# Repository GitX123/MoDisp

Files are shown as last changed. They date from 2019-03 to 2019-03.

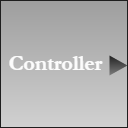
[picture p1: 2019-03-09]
back-end/MoDisp/front-end/image/fg_controller_128.png

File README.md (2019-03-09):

# MoDisp
Robust and flexible modular display system which reconfigures data paths upon hardware change

[back-end]
* Run on Raspberry Pi or C.H.I.P., act as a gateway between the web UI and the MoDisp protocol.
* Mainly contributed by e841018, and also thanks HongCheng Zheng for developing the prototype of the UI.

[controller]
* Run on ATMEGA 328
* James Chan contributed to the firmware, while e841018 designed the PCB.

[bracket]
* Designed by Onshape, publicly available at
  https://cad.onshape.com/documents/cf011c8e0843ee4877112711/w/4f09f0267c82e90f73bca7a8/e/ec47567f47b796b4294d7e92

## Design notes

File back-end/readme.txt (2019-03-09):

[wifi]
sudo nmcli device wifi connect <ssid> password <password> ifname wlan0
sudo nmcli device wifi connect "Obtaining IP address..." password 3.141592 ifname wlan0

[start]
MoDisp/init.sh

[i2cdetect]
/usr/sbin/i2cdetect -y 1

[shutdown]
sudo halt

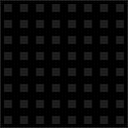
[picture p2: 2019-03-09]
back-end/MoDisp/front-end/image/bg_module_128.png

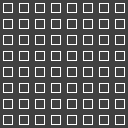
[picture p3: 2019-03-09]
back-end/MoDisp/front-end/image/fg_dbd_128.png

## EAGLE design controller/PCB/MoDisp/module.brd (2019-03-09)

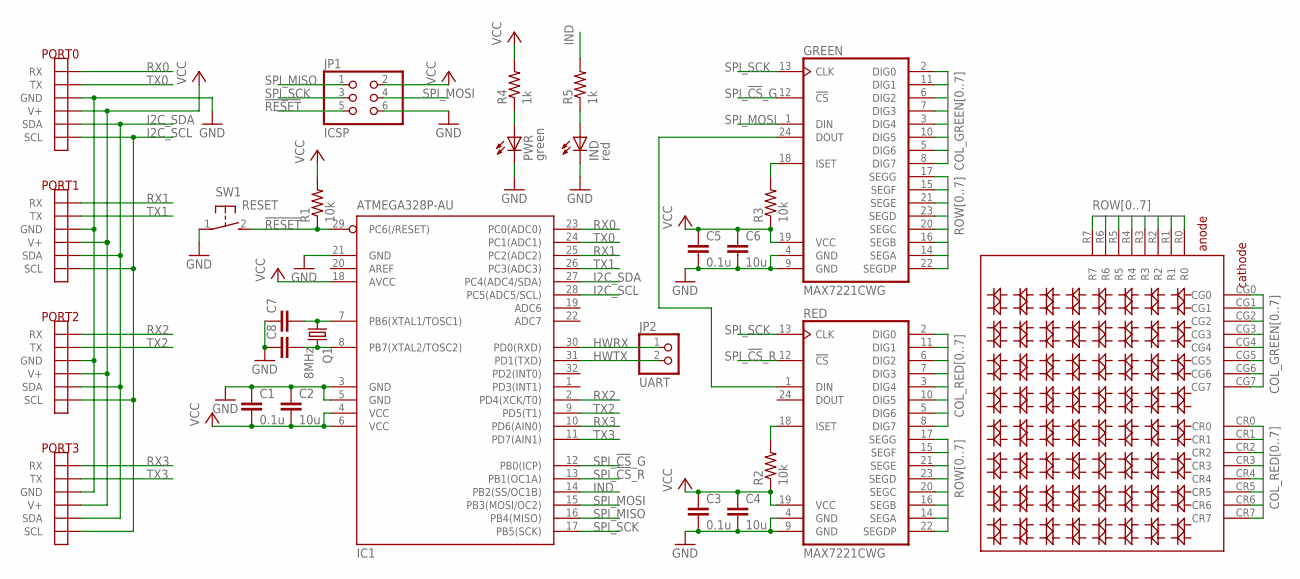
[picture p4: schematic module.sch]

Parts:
C1, C3, C5: 0.1u; C0805
C2, C4, C6: 10u; C1206
C7, C8: C-EUC0805; C0805
GREEN: MAX7221CWG; SO24L
IC1: ATMEGA328P-AU; TQFP32-08
IND: red; CHIPLED_0805
JP1: ICSP; 2X03
JP2: UART; 1X02
PORT0, PORT1, PORT2, PORT3: PORT
PWR: green; CHIPLED_0805
Q1: 8MHz; HC49UP
R1, R2, R3: 10k; R0805
R4, R5: 1k; R0805
RED: MAX7221CWG; SO24L
SW1: RESET; DTSM-3
U$2: 88LED_MATRIX_BICOLOR_ROW_ANODE; 8*8LED_MATRIX_BICOLOR_ROW_ANODE

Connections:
!RESET!: IC1.29 (PC6(/RESET)), JP1.5, R1.1, SW1.2
COL_GREEN0: GREEN.2 (DIG0), U$2.CG0
COL_GREEN1: GREEN.11 (DIG1), U$2.CG1
COL_GREEN2: GREEN.6 (DIG2), U$2.CG2
COL_GREEN3: GREEN.7 (DIG3), U$2.CG3
COL_GREEN4: GREEN.3 (DIG4), U$2.CG4
COL_GREEN5: GREEN.10 (DIG5), U$2.CG5
COL_GREEN6: GREEN.5 (DIG6), U$2.CG6
COL_GREEN7: GREEN.8 (DIG7), U$2.CG7
COL_RED0: RED.2 (DIG0), U$2.CR0
COL_RED1: RED.11 (DIG1), U$2.CR1
COL_RED2: RED.6 (DIG2), U$2.CR2
COL_RED3: RED.7 (DIG3), U$2.CR3
COL_RED4: RED.3 (DIG4), U$2.CR4
COL_RED5: RED.10 (DIG5), U$2.CR5
COL_RED6: RED.5 (DIG6), U$2.CR6
COL_RED7: RED.8 (DIG7), U$2.CR7
GND: C1.1, C2.1, C3.2, C4.2, C5.2, C6.2, C7.1, C8.1, GREEN.4 (GND), GREEN.9 (GND), IC1.3 (GND), IC1.5 (GND), IC1.21 (GND), IND.C, JP1.6, PORT0.GND_L (GND), PORT0.GND_L_D (GND), PORT0.GND_R (GND), PORT0.GND_R_D (GND), PORT1.GND_L (GND), PORT1.GND_L_D (GND), PORT1.GND_R (GND), PORT1.GND_R_D (GND), PORT2.GND_L (GND), PORT2.GND_L_D (GND), PORT2.GND_R (GND), PORT2.GND_R_D (GND), PORT3.GND_L (GND), PORT3.GND_L_D (GND), PORT3.GND_R (GND), PORT3.GND_R_D (GND), PWR.C, RED.4 (GND), RED.9 (GND), SW1.1
HWRX: IC1.30 (PD0(RXD)), JP2.1
HWTX: IC1.31 (PD1(TXD)), JP2.2
I2C_SCL: IC1.28 (PC5(ADC5/SCL)), PORT0.SCL_L (SCL), PORT0.SCL_L_D (SCL), PORT0.SCL_R (SCL), PORT0.SCL_R_D (SCL), PORT1.SCL_L (SCL), PORT1.SCL_L_D (SCL), PORT1.SCL_R (SCL), PORT1.SCL_R_D (SCL), PORT2.SCL_L (SCL), PORT2.SCL_L_D (SCL), PORT2.SCL_R (SCL), PORT2.SCL_R_D (SCL), PORT3.SCL_L (SCL), PORT3.SCL_L_D (SCL), PORT3.SCL_R (SCL), PORT3.SCL_R_D (SCL)
I2C_SDA: IC1.27 (PC4(ADC4/SDA)), PORT0.SDA_L (SDA), PORT0.SDA_L_D (SDA), PORT0.SDA_R (SDA), PORT0.SDA_R_D (SDA), PORT1.SDA_L (SDA), PORT1.SDA_L_D (SDA), PORT1.SDA_R (SDA), PORT1.SDA_R_D (SDA), PORT2.SDA_L (SDA), PORT2.SDA_L_D (SDA), PORT2.SDA_R (SDA), PORT2.SDA_R_D (SDA), PORT3.SDA_L (SDA), PORT3.SDA_L_D (SDA), PORT3.SDA_R (SDA), PORT3.SDA_R_D (SDA)
IND: IC1.14 (PB2(SS/OC1B)), R5.2
unnamed: C7.2, IC1.7 (PB6(XTAL1/TOSC1)), Q1.1
unnamed: C8.2, IC1.8 (PB7(XTAL2/TOSC2)), Q1.2
unnamed: GREEN.18 (ISET), R3.2
unnamed: GREEN.24 (DOUT), RED.1 (DIN)
unnamed: PWR.A, R4.1
unnamed: IND.A, R5.1
unnamed: R2.2, RED.18 (ISET)
ROW0: GREEN.17 (SEGG), RED.17 (SEGG), U$2.R0
ROW1: GREEN.15 (SEGF), RED.15 (SEGF), U$2.R1
ROW2: GREEN.21 (SEGE), RED.21 (SEGE), U$2.R2
ROW3: GREEN.23 (SEGD), RED.23 (SEGD), U$2.R3
ROW4: GREEN.20 (SEGC), RED.20 (SEGC), U$2.R4
ROW5: GREEN.16 (SEGB), RED.16 (SEGB), U$2.R5
ROW6: GREEN.14 (SEGA), RED.14 (SEGA), U$2.R6
ROW7: GREEN.22 (SEGDP), RED.22 (SEGDP), U$2.R7
RX0: IC1.23 (PC0(ADC0)), PORT0.RX_L (RX), PORT0.RX_L_D (RX)
RX1: IC1.25 (PC2(ADC2)), PORT1.RX_L (RX), PORT1.RX_L_D (RX)
RX2: IC1.2 (PD4(XCK/T0)), PORT2.RX_L (RX), PORT2.RX_L_D (RX)
RX3: IC1.10 (PD6(AIN0)), PORT3.RX_L (RX), PORT3.RX_L_D (RX)
SPI_!CS!_G: GREEN.12 (!CS!), IC1.12 (PB0(ICP))
SPI_!CS!_R: IC1.13 (PB1(OC1A)), RED.12 (!CS!)
SPI_MISO: IC1.16 (PB4(MISO)), JP1.1
SPI_MOSI: GREEN.1 (DIN), IC1.15 (PB3(MOSI/OC2)), JP1.4
SPI_SCK: GREEN.13 (CLK), IC1.17 (PB5(SCK)), JP1.3, RED.13 (CLK)
TX0: IC1.24 (PC1(ADC1)), PORT0.TX_R (TX), PORT0.TX_R_D (TX)
TX1: IC1.26 (PC3(ADC3)), PORT1.TX_R (TX), PORT1.TX_R_D (TX)
TX2: IC1.9 (PD5(T1)), PORT2.TX_R (TX), PORT2.TX_R_D (TX)
TX3: IC1.11 (PD7(AIN1)), PORT3.TX_R (TX), PORT3.TX_R_D (TX)
VCC: C1.2, C2.2, C3.1, C4.1, C5.1, C6.1, GREEN.19 (VCC), IC1.4 (VCC), IC1.6 (VCC), IC1.18 (AVCC), JP1.2, PORT0.V+_L (V+), PORT0.V+_L_D (V+), PORT0.V+_R (V+), PORT0.V+_R_D (V+), PORT1.V+_L (V+), PORT1.V+_L_D (V+), PORT1.V+_R (V+), PORT1.V+_R_D (V+), PORT2.V+_L (V+), PORT2.V+_L_D (V+), PORT2.V+_R (V+), PORT2.V+_R_D (V+), PORT3.V+_L (V+), PORT3.V+_L_D (V+), PORT3.V+_R (V+), PORT3.V+_R_D (V+), R1.2, R2.1, R3.1, R4.2, RED.19 (VCC)

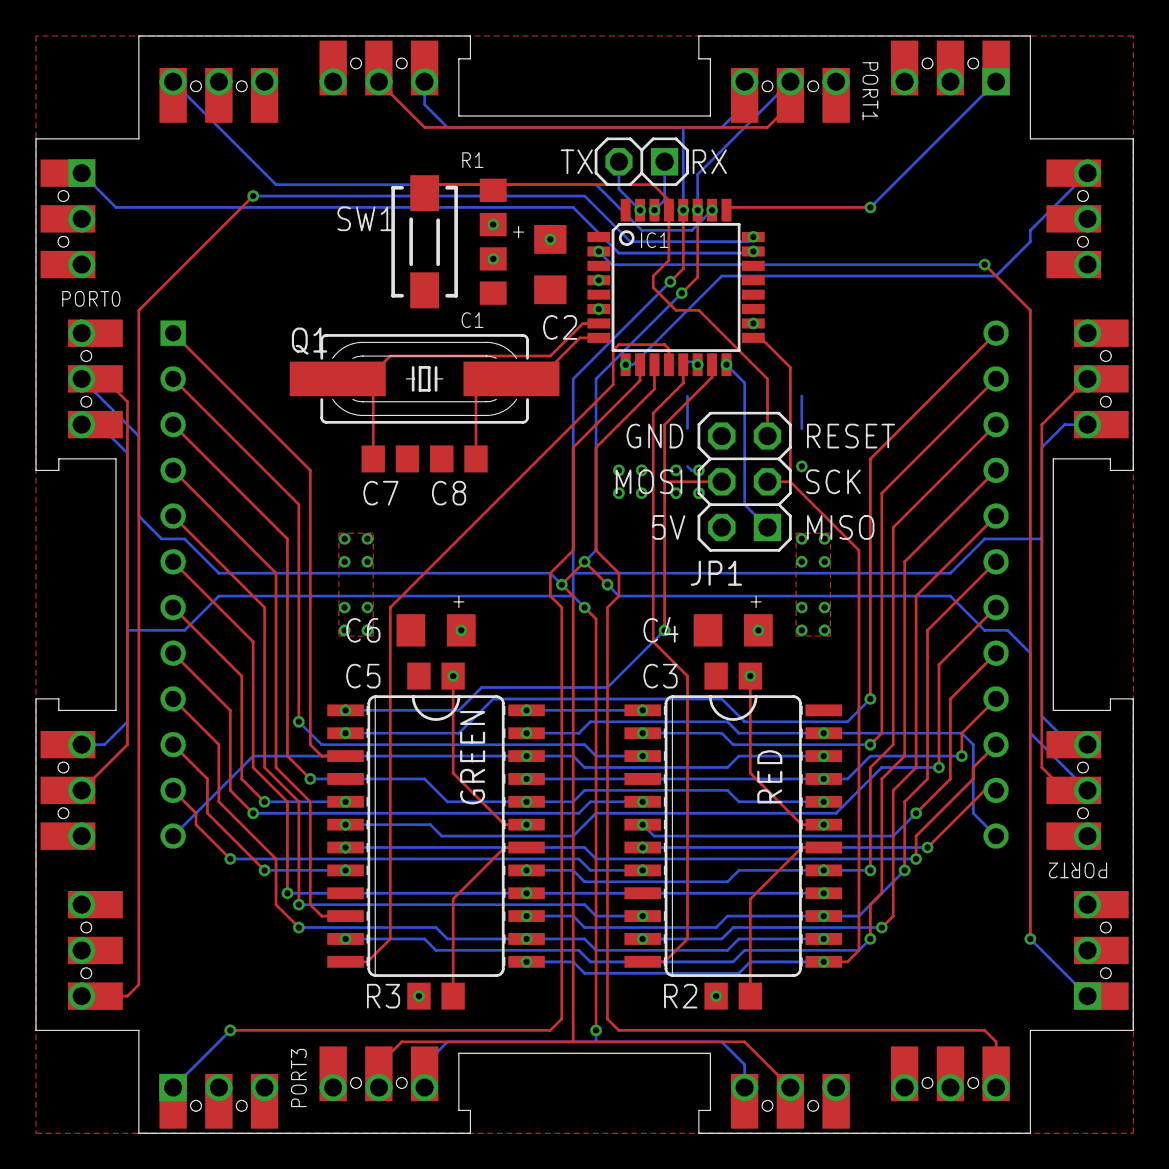
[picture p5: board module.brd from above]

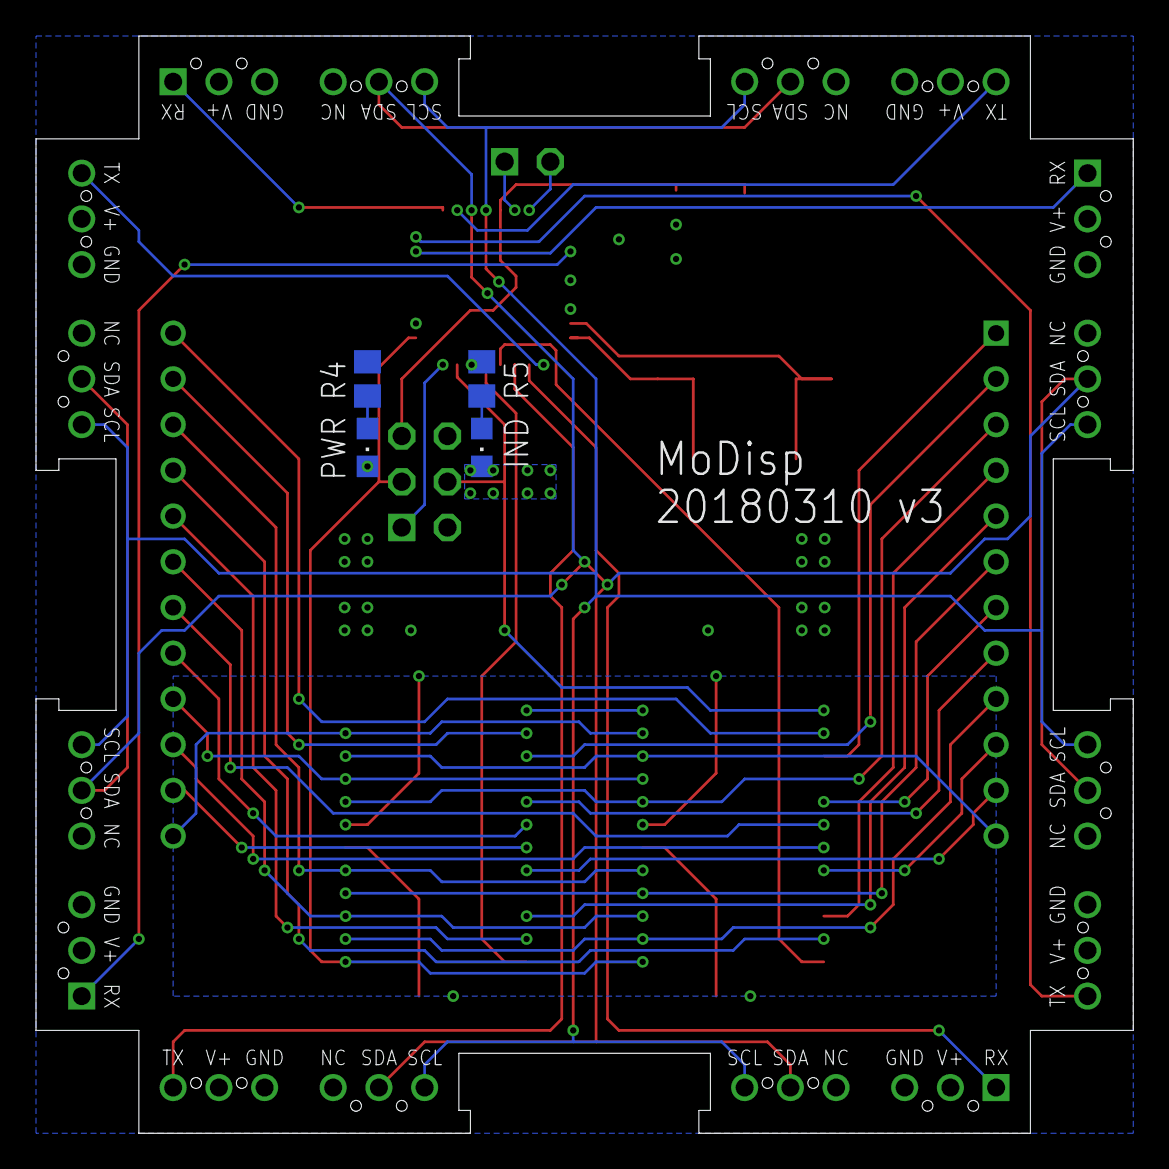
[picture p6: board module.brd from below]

Board: 2 copper layers, 61.0 x 61.0 mm, 27 parts (4 on the bottom side), 52 nets.

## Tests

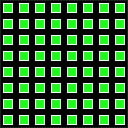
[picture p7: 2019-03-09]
back-end/MoDisp/front-end/image/bg_test_green_128.png

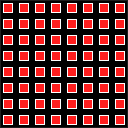
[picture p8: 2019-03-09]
back-end/MoDisp/front-end/image/bg_test_red_128.png

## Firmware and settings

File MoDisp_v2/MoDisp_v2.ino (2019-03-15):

/* select "Tools->ATmega328 on breadboard 8MHz" to use internal clock */
#include <stdint.h>
#include <avr/interrupt.h>
#include <avr/wdt.h>
#include <util/delay.h>
#include "operation.h"

/* max7221 select pins */
#define G_SS 8
#define R_SS 9

/* --- temp --- */
uint8_t test_img[8] = {0xff, 0, 0xff, 0, 0xff, 0, 0xff, 0};
/* --- Global Variables --- */
uint8_t op;
bool hasAddress = false;
uint16_t myAddress; // address of this module s{row(x),column(y)}
uint8_t parent_position;
uint8_t PORT_DIR[4]; // PORT:index , content: direction
bool isConnect[4] = {false}; // connection status
/* --- I2C --- */
volatile uint8_t dir, i2c_addr = 0, i2c_addr_last = 0; // current i2c data
/* --- Ports --- */
/* All serial ports are inverse logic(internal pull up)*/
const uint8_t rx[4] = {14, 16, 4, 6};
const uint8_t tx[4] = {15, 17, 5, 7};
SoftwareSerial UART0(rx[0], tx[0], true);
SoftwareSerial UART1(rx[1], tx[1], true);
SoftwareSerial UART2(rx[2], tx[2], true);
SoftwareSerial UART3(rx[3], tx[3], true);
/* --- Image --- */
volatile uint8_t image[8];
volatile uint8_t intensity_G, intensity_R;
/* --- Timer --- */
volatile bool dispEnable = false;
volatile bool loadEnable = false;

void timer_setup() {
  TCNT1 = 64286; // 10ms at 8MHz
  TCCR1A = 0x00;
  TCCR1B = (1 << CS11) | (1 << CS10); // 64 prescaler
}

ISR(TIMER1_OVF_vect) {
  static bool colorToggle = true;
  if (loadEnable) {
    transform(image);
    disp(G_SS, intensity_G, image);
    disp(R_SS, intensity_R, image);
    loadEnable = false;
  }
  if (dispEnable) {
    if (colorToggle) {
      // shutdown red, enable green
      max7221(R_SS, SHUTDOWN, 0x00);
      max7221(G_SS, SHUTDOWN, 0x01);
    }
    else {
      // shutdown green, enable red
      max7221(G_SS, SHUTDOWN, 0x00);
      max7221(R_SS, SHUTDOWN, 0x01);
    }
    colorToggle = !colorToggle;
  }
  else {
    // turn off display
    max7221(G_SS, SHUTDOWN, 0x00);
    max7221(R_SS, SHUTDOWN, 0x00);
  }
  TCNT1 = 64286;
}

void setup() {
  //  MCUSR = 0;
  //  WDTCSR = 0;
  MCUSR = 0; // clear WDT reset flag
  wdt_disable(); // disable WDT reset
  
  SPI.begin();
  Serial.begin(9600);

// not sure why this will fail
//  Wire.begin(127); // fake i2c slave for reset function
//  TWAR |= (1 << TWGCE);
//  Wire.onReceive(fakeReceiveEvent);
  
  module_setup();
  timer_setup();

  Serial.println("reset");
  requestAddress();
  if (myAddress != plane_center)
    wait_i2cAddr();
}

void loop() {
  /* polling 4 serial ports
    probably change to interrupt-driven*/
  for (uint8_t i = 0; i < 4; i++) {
    bool connection = !(digitalRead( rx[PORT[i]] ));
    if (connection) { // connected
      listenPort(PORT[i]);
      _delay_ms(10);
      if (availablePort(PORT[i])) {
        op = readPort(PORT[i]);
        action(i, op);
      }
    }
    else {
      // connection status changed
      if (connection != isConnect[i]) {
        // check connection again
        // if disconnected: note controller to reset all modules: reset_i2c = true
        _delay_ms(200); // time for manually reset
        connection = connect_check(PORT[i]);
      }
    }
    isConnect[i] = connection; // refresh connection status
  }
}

void fakeReceiveEvent(int bytes) {
  if (Wire.available()) {
    cli();
    WDTCSR |= (1 << WDE);
    sei();
    while (1);
  }
}

void receiveEvent(int bytes) {
  if (Wire.available()) {
    uint8_t i2c_op = Wire.read();

    switch (i2c_op) {
      // perform actions according to op
      case (I2C_RST):
        cli();
        WDTCSR |= (1 << WDE); // enable WDT reset
        sei();
        //        wdt_enable(WDTO_15MS);
        while (1); // lock until reset
        break;
      case (I2C_ADDR):
        if (Wire.available() >= 2) {
          dir = Wire.read();
          i2c_addr = Wire.read();
        }
        //        sendI2CAddr(dir, i2c_addr); this function in I2C cause trouble, put this into normal flow
        break;
      case (I2C_IMAGE):
        if (Wire.available() >= 10) {
          for (uint8_t i = 0; i < 8; i++)
            image[i] = Wire.read();
          intensity_G = Wire.read();
          intensity_R = Wire.read();
        }
        break;
      case (I2C_DISP): // refresh image-related data
        dispEnable = true;
        loadEnable = true;
        TIMSK1 = (1 << TOIE1); // enable timer
        sei();
        break;
      case (I2C_SHUTDOWN):
        dispEnable = false;
        TIMSK1 &= ~(1 << TOIE1); // disable timer
        break;
      case (I2C_TEST):
        break;
      default: break;
    }
  }
}

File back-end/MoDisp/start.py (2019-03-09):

#===============================================================================
# manual switches

DEBUGGING = False
USING_PI = False
USING_BROKER = False
STATIC_ADDRESS = True

#===============================================================================
# imports

# control
from threading import Thread, Lock
from time import time, sleep

# web
from flask import Flask, send_from_directory
from eventlet import wsgi
import eventlet
import socketio

# physical
from heapq import heappush, heappop
try:
	# uart
	from serial import Serial
	# i2c
	from smbus2 import SMBusWrapper
	ONLINE_PHY = True
except ImportError:
	ONLINE_PHY = False
	print('physical side: testing in off-line mode')

#===============================================================================
# global variables

class Reset(Exception):
	pass

if USING_BROKER:
	class I2CError(Exception):
		pass

# control
lock = Lock()
web_thrd = 'to init'
phy_thrd = 'to init'

# web
fnc = {}

# physical
ser_port = '/dev/ttyAMA0' if USING_PI else '/dev/ttyS0'	# serial port name
bus_num = 1	# i2c bus number
i2c_heap = 'to init'
phy = 'to init'
phy_order = 'to init'
phy_flag = 'to init'	# phy updated, need to emit
reset_flag = False

# direction
dx = [-1,0,1,0]
dy = [0,1,0,-1]

# op code
uart_op = {
	'RQ_ADDR'			:0,	# request address
	'RQ_SEND'			:1,	# request sending data
	'SEND_ACK'			:10,# sending acknowledged
	'SEND_DENY'			:11,# sending denied
	'OUT_OF_BOUND'		:12,# address requested is off limit (val<0 or val>255)
	'CONTENT_ADDR'		:13,# instruct the following 2 bytes are address
	'CONTENT_I2C_ADDR'	:14,# I2C address
	'RESET' 			:19,# reset request
}
uart_op_name = {}
for name, code in uart_op.items():
	byte = bytes([code])
	uart_op[name] = byte
	uart_op_name[byte] = name
i2c_op = {
	'I2C_RST'			:20,# I2C message reset
	'I2C_ADDR'			:21,# Distribute I2C address
	'I2C_IMAGE'			:22,# fetch image information
	'I2C_DISP'			:23,# display image(refresh frame - load data)
	'I2C_SHUTDOWN'		:24,# turn off display
	'I2C_TEST'			:25,# 
}

#===============================================================================
# functions

#-------------------------------------------------------------------------------
# web

def server():

	# http server
	app = Flask(__name__)
	@app.route('/')
	def index():
		return send_from_directory('front-end', 'index.html')
	@app.route('/<path:path>')
	def send_root(path):
		return send_from_directory('front-end', path)

	# socket
	sio = socketio.Server()
	app = socketio.Middleware(sio, app)
	@sio.on('connect')
	def connect_cb(sid, environ):
		print('connected:',sid)
		global phy_flag
		phy_flag = True
	@sio.on('disconnect')
	def disconnect_cb(sid):
		print('disconnected:',sid)

	# force phy emitted
	@sio.on('dev')
	def dev_cb(sid, data):
		print('develop data received:',data)
		global phy_flag
		phy_flag = True
	# python-socketio multi-thread problem work-around
	@sio.on('poll_phy')
	def poll_cb(sid):
		lock.acquire()
		global phy_flag
		if phy_flag:
			sio.emit('phy', [phy, phy_order])
			phy_flag = False
			print('phy emitted')
		lock.release()

	# web->physical
	@sio.on('fnc')
	def fnc_cb(sid, data):
		global fnc
		fnc = data
		print('fnc received')
		i2c_scatter_image()
	@sio.on('reset')
	def reset_cb(sid):
		print('reset from client',sid)
		web_reset()

	# file
	file_list = ['test 1', 'test 0']
	file = {
		'test 1':{'126': {'127': {'tp': 'ctrl'}}, '127': {'126': {'tp': 'dbd', 'bmp': [24, 24, 36, 36, 66, 66, 129, 255, 15, 0]}, '127': {'tp': 'dbd', 'bmp': [255, 129, 129, 129, 129, 129, 129, 255, 15, 0]}, '128': {'tp': 'dbd', 'bmp': [255, 129, 66, 66, 36, 36, 24, 24, 15, 0]}}, '128': {'127': {'tp': 'dbd', 'bmp': [60, 66, 129, 129, 129, 129, 66, 60, 15, 0]}}, 'o': {'px': 126, 'py': 128}},
		'test 0':{'126': {'127': {'tp': 'ctrl'}}, '127': {'127': {'tp': 'dbd', 'bmp': [254, 254, 192, 254, 254, 192, 192, 192, 15, 0]}}, '128': {'127': {'tp': 'dbd', 'bmp': [216, 216, 216, 216, 216, 216, 223, 223, 15, 0]}}, '129': {'127': {'tp': 'dbd', 'bmp': [127, 127, 96, 127, 127, 96, 127, 127, 15, 0]}}, 'o': {'px': 126, 'py': 128}},
	}
	@sio.on('flie_list')
	def flie_list_cb(sid):
		print('file_list served')
		return file_list
	@sio.on('file_load')
	def file_load_cb(sid,data):
		print('file "'+data+'" served')
		return file[data]
	@sio.on('file_save')
	def file_save_cb(sid,data):
		file[data['name']] = data['fnc']
		if data['name'] not in file_list:
			file_list.append(data['name'])
		print('file "'+data['name']+'" saved')
	@sio.on('file_del')
	def file_del_cb(sid,data):
		del file[data]
		file_list.remove(data)
		print('file "'+data+'" deleted')
	
	# start wsgi server, following line is blocking
	eventlet.wsgi.server(eventlet.listen(('', 8080)), app, log_output=False)

#-------------------------------------------------------------------------------
# physical

def occupied(dict,x,y):
	if str(x) in dict:
		if str(y) in dict[str(x)]:
			return True
	return False

def byte_to_op_name(bytedata):
	if bytedata == b'':
		return 'timeout'
	return uart_op_name.get(bytedata, hex(bytedata[0]))

# UART non-blocking read
def nb_read(ser,timeout=None):
	if timeout==None:
		non_stop = True
	else:
		non_stop = False
		end_time = time()+timeout
	while non_stop or time()<end_time:
		lock.acquire()
		if ser.in_waiting>0:
			rd = ser.read()
			lock.release()
			return rd
		lock.release()
		if reset_flag:
			raise Reset()
	return b''

# UART wait
# wait for <op_dict> at most <try_max> times, otherwise return False
# try_max==None: try forever
def wait(ser, op_dict, try_max=None, timeout=None):
	print('waiting for',op_dict)
	try_cnt = 0
	hit = False
	while try_max==None or try_cnt<try_max:
		op_rx = byte_to_op_name(nb_read(ser,timeout))
		print('rx',op_rx)
		if op_rx in op_dict:
			hit = True
			break
		else:
			try_cnt += 1
	if hit:
		print('after',try_cnt,'tries')
		return op_rx
	else:
		print('stop waiting for',op_dict,'after',try_cnt,'tries')
		return 'fail'

# UART write
def write(ser, op, *content):
	lock.acquire()
	print('tx',op,content)
	ser.write(uart_op[op])
	ser.write(bytes(content))
	lock.release()

def i2c_write(addr, op, data=[]):
	if USING_BROKER:
		print('i2c',addr,'write',op,data)
		ser_global.write(bytes([addr,i2c_op[op]]+data))
	else:
		lock.acquire()
		print('i2c',addr,'write',op,data)
		try:
			with SMBusWrapper(bus_num) as bus:
				bus.write_i2c_block_data(addr, i2c_op[op], data)
		finally:
			lock.release()

def i2c_image(i_s, j_s):
	addr = phy[i_s][j_s][0]
	if occupied(fnc,int(i_s),int(j_s)):
		bmp = fnc[i_s][j_s]['bmp']
	else:
		bmp = [0,0,0,0,0,0,0,0,0,0]
	try:
		i2c_write(addr, 'I2C_IMAGE', bmp)
	except Exception as ex:
		print(type(ex).__name__+': image scatter failed, ignore')
		print(ex)

def i2c_disp():
	try:
		i2c_write(0, 'I2C_DISP', [])
	except Exception as ex:
		print(type(ex).__name__+': image display failed, ignore')
		print(ex)

def i2c_scatter_image():
	if ONLINE_PHY:
		for i_s in phy:
			for j_s in phy[i_s]:
				i2c_image(i_s,j_s)
		i2c_disp()
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

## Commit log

2019-03-09 Add files via upload
    20180310 v3
    [module.brd, module.sch]
2019-03-09 add link to the bracket design
